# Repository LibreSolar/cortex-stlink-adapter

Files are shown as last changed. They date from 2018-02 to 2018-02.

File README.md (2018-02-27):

# Cortex ST-Link Adapter

This adapter allows to connect the ST-Link V2 (STM32 Nucleo boards) to be connected to the small 10-pin Cortex standard connectors.

The ST-Link can be used as a serial wire debug (SWD) interface.

## Schematic

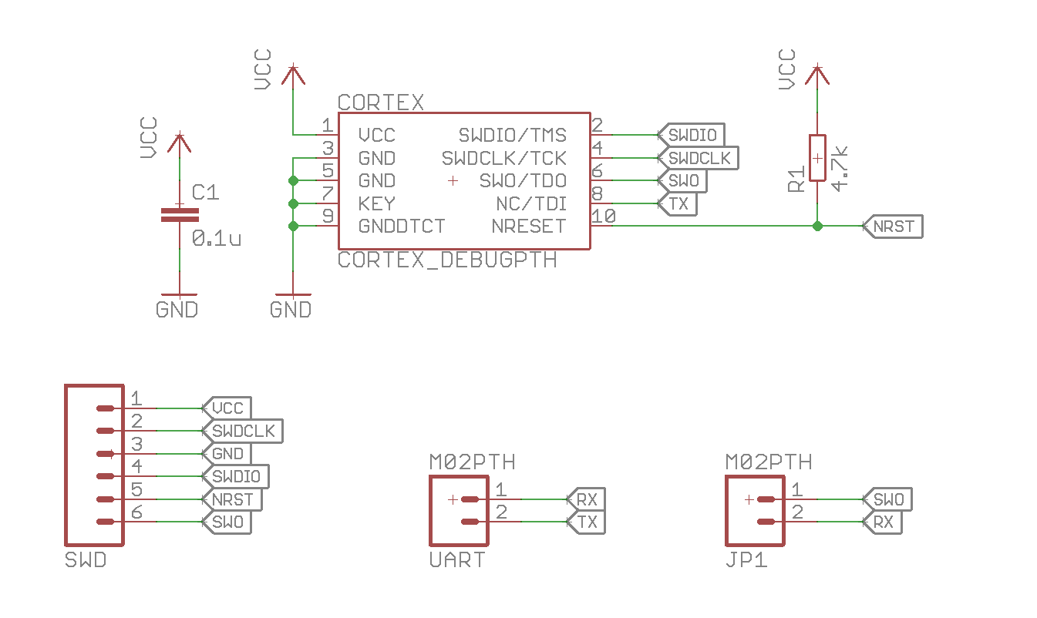
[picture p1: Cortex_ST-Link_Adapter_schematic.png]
Schematic of adapter


The jumper JP1 can be used to connect the SWO pin (serial wire output) to the RX pin of the nucleo board, thus allowing serial communications with MCUs which don't have SWO (Cortex M0 like STM32F072 for example). This works only if the Cortex SWO pin is wired to a TX pin of the MCU, of course.

The pull-up resistor is useful to put NRST to a defined state.

The additional capacitor C1 can be used to stabilize the supply voltage, but might not be necessary.

## Original pictures

### Top side
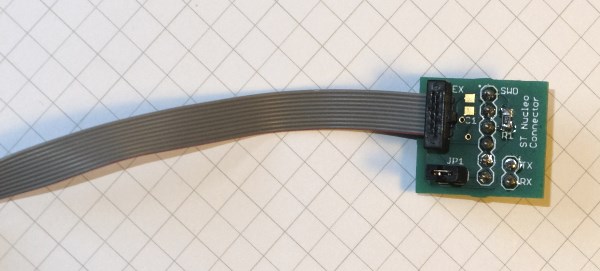
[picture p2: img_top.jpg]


### Bottom side (fits to ST-Link on Nucleo Board)
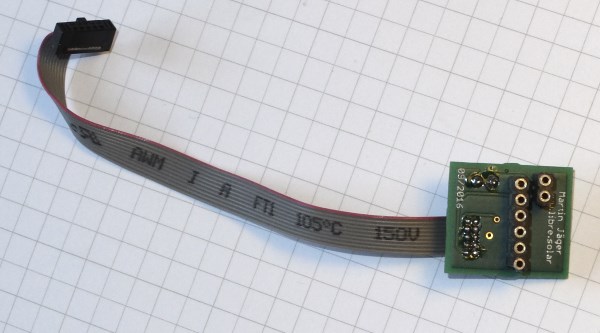
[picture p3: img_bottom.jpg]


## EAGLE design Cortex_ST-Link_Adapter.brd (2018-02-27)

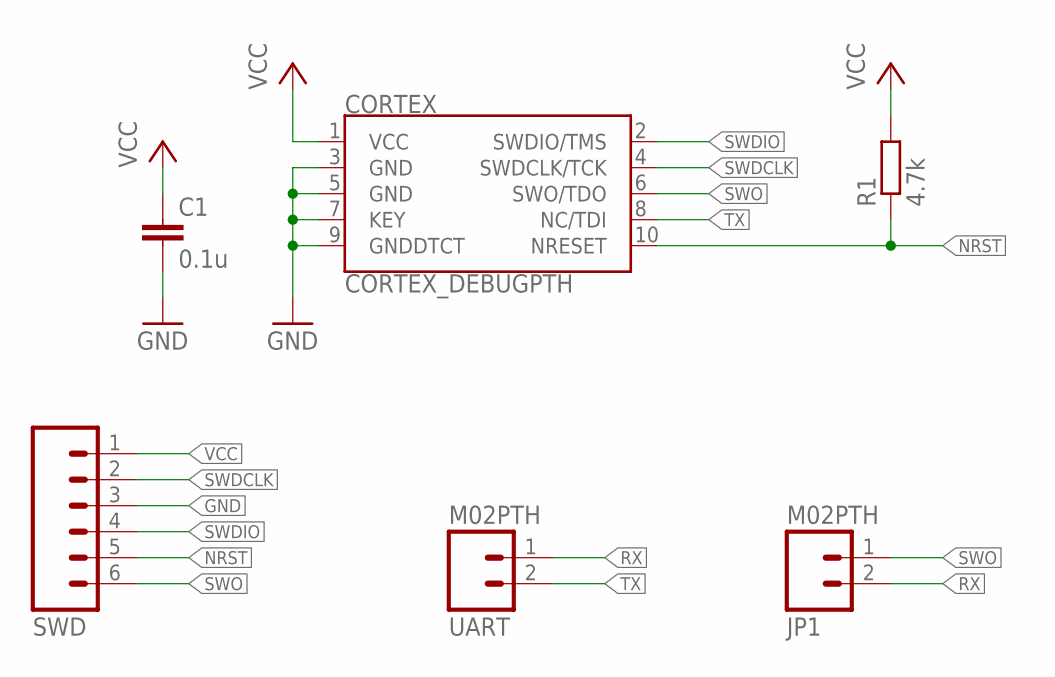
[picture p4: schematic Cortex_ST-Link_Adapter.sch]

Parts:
C1: 0.1u; C0805
CORTEX: CORTEX_DEBUGPTH; 2X5-PTH-1.27MM
JP1: M02PTH; 1X02
R1: 4.7k; R0805
SWD: M06SILK_FEMALE_PTH; 1X06
UART: M02PTH; 1X02

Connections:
GND: C1.2, CORTEX.3 (GND), CORTEX.5 (GND), CORTEX.7 (KEY), CORTEX.9 (GNDDTCT), SWD.3
NRST: CORTEX.10 (NRESET), R1.1, SWD.5
RX: JP1.2, UART.1
SWDCLK: CORTEX.4 (SWDCLK/TCK), SWD.2
SWDIO: CORTEX.2 (SWDIO/TMS), SWD.4
SWO: CORTEX.6 (SWO/TDO), JP1.1, SWD.6
TX: CORTEX.8 (NC/TDI), UART.2
VCC: C1.1, CORTEX.1 (VCC), R1.2, SWD.1

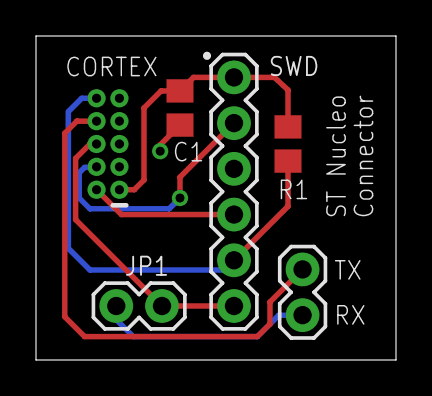
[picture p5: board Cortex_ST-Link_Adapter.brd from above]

Board: 2 copper layers, 20.0 x 18.0 mm, 6 parts (0 on the bottom side), 8 nets.

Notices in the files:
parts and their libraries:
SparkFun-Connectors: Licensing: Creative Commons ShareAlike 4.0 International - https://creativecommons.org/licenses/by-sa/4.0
